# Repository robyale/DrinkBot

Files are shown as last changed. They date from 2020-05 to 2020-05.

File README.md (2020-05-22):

# DrinkBot
## Installation and Use
To install the required dependencies, use the following command
```
pip install -r requirements.txt
```

This project is based off of the [hackster.io smart bartender](https://github.com/HackerShackOfficial/Smart-Bartender#readme), so this will follow much of the same guidelines as their machine.

## Raspberry Pi
You must install the following on your Raspberry Pi:
- [Python 3.x](https://www.python.org/downloads/)
- [pip](https://www.raspberrypi.org/documentation/linux/software/python.md)

## Enable SPI and I2C
Our OLED screen will be using SPI. To enable, type the following into the terminal.
```
raspi-config
```
Navigate to interfacing options and select SPI.
To enable I2C, type the following in the terminal.
```
sudo vim /etc/modules
```
Then press i, and paste the following into the file.
```
i2c-bcm2708
i2c-dev
```
press esc then zz to exit

## OLED Display
The methods the HackerShack team used for the display have since depreciated. Adafruit put together a [great tutorial](https://learn.adafruit.com/monochrome-oled-breakouts/overview) on making the OLED work. You simply need to run the command 
```
pip install adafruit_ssd1306
```
and the display should work.

## Run at Startup
To enable running at startup, simply use the pwd command in the repository to get the path to your repository. Copy this, and then type 
```
sudo vim /etc/rc.local
```
Press i to edit, and then add the following lines right before the last line:
```
cd your/path/here
sudo python main.py
```

## Background
When I first saw the HackerShack team build this, I thought it would be a fun side project to get out of my comfort zone of C++ and Arduino and get more familiar with python and Raspberry Pi. What I thought was a fun side project turned into an overhaul of the original design. Multiple dependencies had depreciated and ended up not working, so I had to redesign the code to get everything working. See changes below for a full list of changes.
## This Project
My goal for this project is to 1) learn the basics of circuitPython for microcontrollers, 2) learn the basics of using a Raspberry PI, and 3) grow my skills in using Fusion 360 CAD software. Simply write the drinks you want in the drinks.py file, add the ingredients to the pump configuration file pumps.py, and fire up your Raspberry Pi running main.py to get drinks automatically made for you at the press of a button! Some installation required.
## Picture of Model
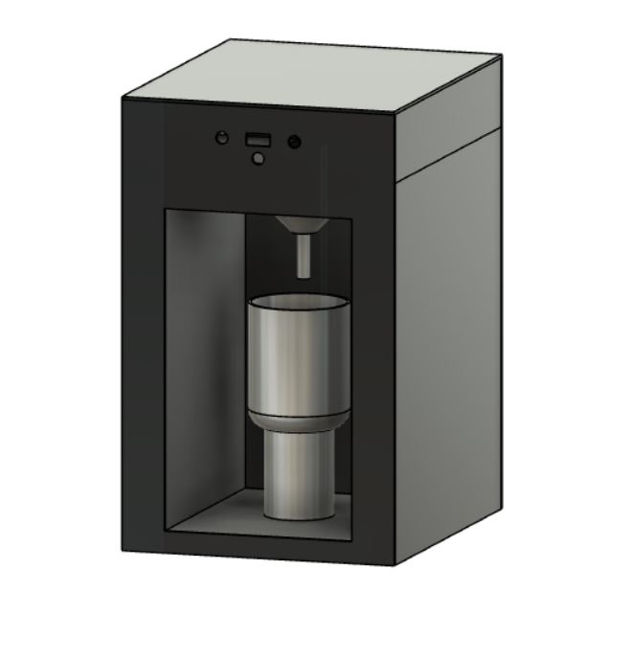
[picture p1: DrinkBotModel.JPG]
Model of the DrinkBot

## Changes
### Hardware
- Added a third button to support previous, next, and select
- Expanded pumps from 6 pumps to 12 pumps for added drink options
- Moved electronics from the bottom to the top of the DrinkBot to prevent liquid leaking onto electronics
- Moved display to top for easier viewing
- Added a larger display
- Pumps moved to the inside of the DrinkBot for a sleek look
- Changed the lights from digital to analog
- Made the DrinkBot taller to support tumblers
### Software
- Added a display module to handle displaying menu items
- Display now shows multiple items per page
- Added a button debounce module to prevent multiple button clicks
- Removed json in favor of nested python dictionaries
- Added software to control analog lights
- Added shot menu for shots of ingredients
- Refactored menu module
- Designed new DrinkBot in Fusion 360
## Future Versions and Considerations
While it was nice to shake things up and use different software/hardware combinations, Arduino would have made this project much simpler. Arduino has much more libraries to support the devices I used, and it is easier to set up the GPIO pins. If I were to redo this, I would have used a Raspberry Pi zero, or fully converted over to Arduino. The Raspberry Pi is simply more powerful than what is needed by this project. Also, the peristaltic pumps I used were too slow; it took almost 20 seconds to make a drink. I didn't need the precision given by the pumps, and I would instead opt for a faster, less accurate pump. A friend of mine used aquatic pumps for a project of his, and he didn't notice much of a drop in accuracy. I would opt to use those pumps for faster drink making. I heavily considered making this a wifi enabled DrinkBot. However, someone would have to make sure there is a glass inside the machine, and then have to go get the drink after it has been made. The wifi wouldn't add any value to the DrinkBot; it would have been a complete gimmick. I also wanted to use 3D printing for some of the parts on the DrinkBot. However, Coronavirus shut down our 3D printer lab, and I was left without access to one. For future versions, I would 3D-print a support for the funnel, braces for the tubing/wiring, a front plate for the display, and brackets for the pumps. I also would include hinges for the side electronics door and the back pump door. The plastic used is too thin for screws, so alternative methods for attaching the hinges would have to be explored.

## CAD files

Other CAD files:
DrinkBot.f3d

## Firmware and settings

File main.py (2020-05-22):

import board
import digitalio
import adafruit_ssd1306
import RPi.GPIO as GPIO
import time
import threading
import sys

from menu import *
from drinks import drinkList, ingredients
from pumps import pumps
from debounce import ButtonHandler
from display import Display

# Display Dimensions
WIDTH = 128
HEIGHT = 64
BORDER = 5
ROWS = 5

# Button Pins
LEFT_BTN_PIN = 23
RIGHT_BTN_PIN = 24
SELECT_BTN_PIN = 18
BOUNCE = 10

# OLED Screen Pins
RESET_PIN = board.D4
CS_PIN = board.D5
DC_PIN = board.D6

# LED Constants
RED_PIN = 17
GREEN_PIN = 22
BLUE_PIN = 27
FADE_SLEEP = 0.01

# Pump Flow Rate
FLOW_RATE = 60.0/100.0


class Bartender(MenuDelegate):
    def __init__(self):
        self.running = False

        # Set the oled screen height
        self.screen_width = WIDTH
        self.screen_height = HEIGHT

        # Set up buttons
        self.btn1Pin = LEFT_BTN_PIN
        self.btn2Pin = RIGHT_BTN_PIN
        self.btn3Pin = SELECT_BTN_PIN

        # Configure interrups for buttons
        GPIO.setup(self.btn1Pin, GPIO.IN, pull_up_down=GPIO.PUD_UP)
        GPIO.setup(self.btn2Pin, GPIO.IN, pull_up_down=GPIO.PUD_UP)
        GPIO.setup(self.btn3Pin, GPIO.IN, pull_up_down=GPIO.PUD_UP)

        # Configure Screen
        spi = board.SPI()
        oled_reset = digitalio.DigitalInOut(RESET_PIN)
        oled_cs = digitalio.DigitalInOut(CS_PIN)
        oled_dc = digitalio.DigitalInOut(DC_PIN)
        self.oled = adafruit_ssd1306.SSD1306_SPI(WIDTH, HEIGHT, spi, oled_dc, oled_reset, oled_cs)

        # load the pump configuration
        self.pumps = pumps
        for pump in self.pumps:
            GPIO.setup(pump["pin"], GPIO.OUT, initial=GPIO.HIGH)
        
        # Configure LED Pins
        GPIO.setup(RED_PIN, GPIO.OUT)
        GPIO.setup(GREEN_PIN, GPIO.OUT)
        GPIO.setup(BLUE_PIN, GPIO.OUT)
        
        # set RGB for lights
        self.red = GPIO.PWM(RED_PIN, 50)
        self.green = GPIO.PWM(GREEN_PIN, 50)
        self.blue = GPIO.PWM(BLUE_PIN, 50)
        
        # start LEDs
        self.red.start(0)
        self.green.start(0)
        self.blue.start(0)

    # Create up button interrupts with debounce
    def startInterrupts(self):
        self.cb_left = ButtonHandler(self.btn1Pin, self.left_btn, edge='rising', bouncetime=BOUNCE)
        self.cb_left.start()
        GPIO.add_event_detect(self.btn1Pin, GPIO.FALLING, callback=self.cb_left)
        
        self.cb_right = ButtonHandler(self.btn2Pin, self.right_btn, edge='rising', bouncetime=BOUNCE)
        self.cb_right.start()
        GPIO.add_event_detect(self.btn2Pin, GPIO.FALLING, callback=self.cb_right)
        
        self.cb_select = ButtonHandler(self.btn3Pin, self.select_btn, edge='rising', bouncetime=BOUNCE)
        self.cb_select.start()
        GPIO.add_event_detect(self.btn3Pin, GPIO.FALLING, callback=self.cb_select)

    # Stop button interrupts
    def stopInterrupts(self):
        GPIO.remove_event_detect(self.btn1Pin)
        GPIO.remove_event_detect(self.btn2Pin)
        GPIO.remove_event_detect(self.btn3Pin)

    # Initialize the menus
    def initializeMenu(self, drinkList, ingredients):
        # Set up main menu
        myMenu = Menu("Main Menu")
        drinkMenu = Menu("Drink Menu")
        shotMenu = Menu("Shot Menu")

        # Make main menu the parent of sub menus
        drinkMenu.setParent(myMenu)
        shotMenu.setParent(myMenu)

        # Add back buttons
        drinkMenu.addChild(Back("Back"))
        shotMenu.addChild(Back("Back"))

        # Add drinks to drink menu
        for i in drinkList:
            drinkMenu.addChild(MenuItem("drink", i["name"], {"ingredients": i["ingredients"]}))

        # Add shots to shot menu
        for i in ingredients:
            shotMenu.addChild(MenuItem("shot", i["name"], {"ingredients": i["ingredients"]}))

        # Add sub menus
        myMenu.addChild(drinkMenu)
        myMenu.addChild(shotMenu)    
        myMenu.addChild(MenuItem('clean', 'Clean'))

        # Add a menu context for navigation
        self.menuContext = MenuContext(myMenu, self)
        self.filterDrinks(myMenu)

    # Filter available drinks
    def filterDrinks(self, menu):
        for i in menu.children:
            if(i.type == "drink"):
                i.visible = False
                ingredients = i.attributes["ingredients"]
                presentIng = 0
                for ing in ingredients.keys():
                    for p in self.pumps:
                        if (ing == p["value"]):
                            presentIng += 1
                if (presentIng == len(ingredients.keys())): 
                    i.visible = True
            elif (i.type == "menu"):
                self.filterDrinks(i)
                
    # Called when a menu is clicked, routes to appropriate action
    def menuItemClicked(self, menuItem):
        if (menuItem.type == "drink" or menuItem.type == "shot"):
            self.makeDrink(menuItem.name, menuItem.attributes["ingredients"])
            return True
        elif(menuItem.type == "clean"):
            self.clean()
            return True
        return False
    
    # Cleans the tubing
    def clean(self):
        waitTime = 20
        pumpThreads = []

        # cancel any button presses while the drink is being made
        # self.stopInterrupts()
        self.running = True

        # define pump threads
        for pump in self.pumps:
            pump_t = threading.Thread(target=self.pour, args=(pump["pin"], waitTime))
            pumpThreads.append(pump_t)

        # start the pump threads
        for thread in pumpThreads:
            thread.start()

        # start the progress bar
        self.progressBar(waitTime)

        # wait for threads to finish
        for thread in pumpThreads:
            thread.join()

	    # show the main menu
        self.displayMenuItem(self.menuContext.currentMenu)

	    # sleep for a couple seconds to make sure the interrupts don't get triggered
        time.sleep(2)

	    # reenable interrupts
	    # self.startInterrupts()
        self.running = False

    # Display a menu item
    def displayMenuItem(self, menu):
        dsp = Display(self.oled, WIDTH, HEIGHT, ROWS, menu)
        dsp.drawMenu()

    # Make lights glow
    def cycleLights(self):
        # Fade from nothing up to full red
        for i in range(100):
            self.red.ChangeDutyCycle(i)
            time.sleep(FADE_SLEEP)
            
    
        # Now fade from violet (red + blue) down to red
        for i in range(100, -1, -1):
            self.blue.ChangeDutyCycle(i)
            time.sleep(FADE_SLEEP)
        
        # Fade from red to yellow (red + green)
        for i in range(100):
            self.green.ChangeDutyCycle(i)
            time.sleep(FADE_SLEEP)
        
        # Fade from yellow to green
        for i in range(100, -1, -1):
            self.red.ChangeDutyCycle(i)
            time.sleep(FADE_SLEEP)
        
        # Fade from green to teal (blue + green)
        for i in range(100):
            self.blue.ChangeDutyCycle(i)
            time.sleep(FADE_SLEEP)
        
        # Fade from teal to blue
        for i in range(100, -1, -1):
            self.green.ChangeDutyCycle(i)
            time.sleep(FADE_SLEEP)

# Currently a bug prevents cycleLights from stopping
# during an interrupt, causes issues with progress bar
# **TODO**
#     def lightsProgressBar(self, waitTime):
#         # make lights red
#         self.red.ChangeDutyCycle(100)
#         self.green.ChangeDutyCycle(0)
#         self.blue.ChangeDutyCycle(0)
# 
#         fade = waitTime / 200.0
# 
#         # fade to yellow
#         for i in range(100):
#             self.green.ChangeDutyCycle(i)
#             time.sleep(fade)
# 
#         # fade to green
#         for i in range(100, -1, -1):
#             self.red.ChangeDutyCycle(i)
#             time.sleep(fade)

    # Activates pump for specified amount of time
    def pour(self, pin, waitTime):
        GPIO.output(pin, GPIO.LOW)
        time.sleep(waitTime)
        GPIO.output(pin, GPIO.HIGH)

    # Display a progress bar
    def progressBar(self, waitTime):
        dsp = Display(self.oled, WIDTH, HEIGHT, ROWS)
        dsp.progressBar(waitTime)

    # Make the specified drink
    def makeDrink(self, drink, ingredients):
        self.running = True

        # Parse the drink ingredients and spawn threads for pumps
        maxTime = 0
        pumpThreads = []
        for ing in ingredients.keys():
            for pump in self.pumps:
                if ing == pump["value"]:
                    waitTime = ingredients[ing] * FLOW_RATE
                    if (waitTime > maxTime):
                        maxTime = waitTime
                    pump_t = threading.Thread(target=self.pour, args=(pump["pin"], waitTime))
                    pumpThreads.append(pump_t)

        # start the pump threads
        for thread in pumpThreads:
            thread.start()

        # launch a thread to control lighting
        #lightsThread = threading.Thread(target=self.lightsProgressBar, args=(maxTime,))
        #lightsThread.start()

        # start the progress bar
        self.progressBar(maxTime)

        # wait for threads to finish
        for thread in pumpThreads:
            thread.join()

        # show the main menu
        #self.menuContext.showMenu()
        self.displayMenuItem(self.menuContext.currentMenu)

        # stop the light thread
        #lightsThread.do_run = False
        #lightsThread.join()

        # sleep for a couple seconds to make sure the interrupts don't get triggered
        time.sleep(2)
        
        self.running = False

    # Go to previous menu item
    def left_btn(self, ctx):
        if not self.running:
            self.menuContext.currentMenu.before()
            self.menuContext.showMenu()

    # Go to next menu item
    def right_btn(self, ctx):
        if not self.running:
            self.menuContext.currentMenu.next()
            self.displayMenuItem(self.menuContext.currentMenu)

    # Select menu item
    def select_btn(self, ctx):
        print("button press")
        if not self.running:
            self.menuContext.select()

    # Main loop, runs constantly
    def run(self):
        self.startInterrupts()
        # main loop
        try:  
            while True:
                self.cycleLights()
        except KeyboardInterrupt:  
            GPIO.cleanup()       # clean up GPIO on CTRL+C exit  
        GPIO.cleanup()           # clean up GPIO on normal exit 

		#traceback.print_exc()
    
# Start program
bartender = Bartender()
bartender.initializeMenu(drinkList, ingredients)
bartender.run()

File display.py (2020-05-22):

from PIL import Image, ImageDraw, ImageFont
import adafruit_ssd1306
import itertools
import math
import time

# Class to handle displaying menus
class Display(object):
    def __init__(self, oled, width, height, rows = 5, menu = None):
        self.oled = oled
        self.width = width
        self.height = height
        self.rows = rows
        self.menu = menu
        
        self.image = Image.new("1", (width, height))
        self.draw = ImageDraw.Draw(self.image)
        self.font = ImageFont.load_default()

        oled.fill(0)
        oled.show
        
    # Get indices of menu items that can be displayed
    def getVisible(self):
        indices = []
        index = 0
        for item in self.menu.children:
            if(item.visible == True):
                indices.append(index)
            index += 1
        return indices
        
    # Get indices of menu items to display
    def getIndex(self):
        start = 0
        rows = self.rows
        indices = self.getVisible()
        end = len(indices)
        
        # If there has to be more than 1 page
        if(end > rows):
            # Get the current page, and max amount of pages
            curPage = 0
            curPage = math.floor(self.menu.selected / rows) + 1
            maxPage = math.ceil(end / rows)
            strPage = str(curPage) + "/" + str(maxPage)

            # Draw page location in corner
            self.draw.text((self.width-20, 5), strPage, font=self.font, fill=255)

            # Get starting index
            start = (curPage - 1) * rows

            # Determine end index
            if(curPage != maxPage):
                end = curPage * rows
            else:
                end = start + (end % rows)
        
        return list(itertools.islice(indices, start, end))
        
    # Draw the menu
    def drawMenu(self):        
        indices = self.getIndex()
        position = 0
        for i in indices:
            # Get the text to be displayed
            text = self.menu.children[i].name
            # Get dimensions of font
            (font_width, font_height) = self.font.getsize(text)
            # Draw the text
            self.draw.text((5, font_height * position), text, font=self.font, fill=255)
            # If selected, append *
            if(i == self.menu.selected):
                self.draw.text((font_width + 10, font_height * position + 2), "*", font=self.font, fill=255)
            position += 1
        
        # Draw menu
        self.oled.image(self.image)
        self.oled.show()
        
    # Draw the progress bar
    def progressBar(self, waitTime):
        interval = waitTime / 10.0
        for i in range(1, 11):
            self.draw.rectangle((0, 0, i * 10, self.oled.height - 30), outline=255, fill=255)
            self.oled.image(self.image)
            self.oled.show()
            time.sleep(interval)
